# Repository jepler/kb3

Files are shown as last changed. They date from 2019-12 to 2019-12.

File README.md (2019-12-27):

# kb3 - OpenSCAD 3D printable keyboard with TKL layout

I was inspired by [the SiCK-68 keyboard on thingiverse](https://www.thingiverse.com/thing:3478494), but I favor the tenkeyless layout.
In particular, switching between the SiCK-68 and a TKL is difficult because of the compromise in placement of the escape key.
I realized that with a similar "two halves" design, I could print a full tenkeyless layout on my printer, but just barely.
That's when I started my own 3d printable keyboard design in OpenSCAD.

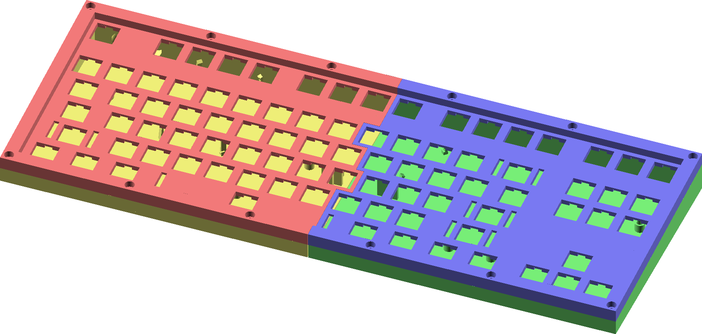
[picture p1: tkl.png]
3D Rendering


# Mechanicals

Aperture sizes are taken from direct measurements, from mechanical drawings of Cherry MX and Kailh keyswitches, and from the excellent (if somewhat bitrotted) [kad](https://github.com/swill/kad) program.
The stabilizer openings are for "Keystar" style stabilizers.

In contrast to SiCK-68, the case halves are joined with M3 screws into heat-set inserts.
Internal electronics are mounted via threaded inserts or little brackets, as appropriate.
A [panel-mount USB connector](https://www.adafruit.com/product/3258) is used, instead of situating the main microcontroller PCB at a fixed location.

# Electronics

This isn't done yet :)
The tenkeyless layout needs 23 I/Os for the "obvious" but inefficient matrix.
This can be dropped by 1 column pretty easily, allowing one pin left over
on an Itsy Bitsy (M4, M0, or AVR 32u4, not the upcoming nRF52840)

# Software

I plan to run CircuitPython, which will mean a need for new code.
CircuitPython can do basic HID (USB and Bluetooth).
However, as far as I've discovered, there aren't any libraries on top of that to facilitate keyboard layers, etc.

# OpenSCAD structure

`cherryplate.scad` functions as a library, and `tkl.scad` creates a particular keyboard.

# Status

See the issues page for items I know need to be worked on.

I think the 3D parts are complete.

# Contributing

I'm not sure this is ready for contributions or even issue reports yet.  
That said, stuff that would be great to do is:
 * Refactor `cherryplate.scad` so it is a good basis for further work
 * Pull items such as alignment pin locations into `cherryplate.scad`
 * Maybe an (external, Python or such) converter from www.keyboard-layout-editor.com layouts to my internal format
 * Contribute other layouts

# Bill of Material

*This bill of material is a work in progress.  Verify it yourself, don't order blindly*

(These are not affiliate links, but I do work for Adafruit)

| Item | Qty | Link | Comments |
|--|--|--|--|
| Filament | ~400g | | I used PLA |
| Keyswitches | 87 | | I'm using Kailh Purple |
| Costar Plate Mounted Clips | 2 * 5 | https://www.wasdkeyboards.com/cherry-mx-plate-mounted-stabilizer-clips-2pcs.html | |
| Costar Keycap Stabilizer Insert | 2 * 5 | https://www.wasdkeyboards.com/cherry-mx-keycap-stabilizer-insert-2pcs.html | |
| Costar Stabilizer Spring for 2x+ Keycaps | 4 * 5 | https://www.wasdkeyboards.com/cherry-mx-stabilizer-spring-for-2x-keycaps.html | |
| Costar Stabilizer Spring for Spacebar | 1 | https://www.wasdkeyboards.com/cherry-mx-stabilizer-spring-for-spacebar.html | |
| M3 x 4mm threaded inserts | 12 | https://www.mcmaster.com/94459A130 | |
| M2 x 2.5mm threaded inserts | 12 | https://www.mcmaster.com/94459A110 | |
| M3 x 8 screws | 12 | | |
| M2 x 6 screws | 8 | | |
| Neopixel strips | 4 | https://www.adafruit.com/product/1426 | |
| Itsy Bitsy M4 Express | 1 | https://www.adafruit.com/product/3800 | Or 32u4 or M0 |
| panel mount micro USB connector | 1 | https://www.adafruit.com/product/3258 | |
| Wiring | | | |

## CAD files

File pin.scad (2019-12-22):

intersection() {
    rotate([90,0,0])
    cylinder(d=3.9, h=16, $fn=32, center=true);

    cube([16, 16, 3.4], center=true);

    linear_extrude(height=6, center=true)
    polygon([
        [-0.5, -8.1],
        [-2.0, -4.1],
        [-2.0,  4.1],
        [-0.5,  8.1],
        [ 0.5,  8.1],
        [ 2.0,  4.1],
        [ 2.0, -4.1],
        [ 0.5, -8.1],
    ]);
}

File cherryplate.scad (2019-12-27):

// https://media.digikey.com/pdf/Data%20Sheets/Cherry%20PDFs/MX%20Series.pdf

////////////////////////////////////////////////////////////////////////
// micro b panel connector
// Overall width: 25mm
// Max height: 10mm (measured)
// Hole spacing: 18mm (per datasheet adafru.it/3258)
// Mounting screws: #4-40

// Create a void for the panel mount micro USB connector,
// connector pointing towards +Z, mounting holes aligned along X
module panelmicrob_void(d_front, d_back, h_spc = 18, maxh = 12, ovw = 26, h_dia =4.5 ) {
    d_ovl = d_back + d_front;
    // 1. Clearance holes for #4-40 screws, length d_front
    translate([-h_spc/2, 0, -.01])
    cylinder(d=h_dia, h=d_front+.01);
    translate([ h_spc/2, 0, -.01])
    cylinder(d=h_dia, h=d_front+.01);
    // 2. hole for the connector itself est 10x5mm
    translate([ 0, 0, -.01])
    linear_extrude(height=h_dia)
    square([11, 6],center=true);
    
    // 3. Cutout for the thing itself, length d_bac
    translate([0, 0, -d_back])
    linear_extrude(height=d_back)
    hull() {
        translate([-h_spc/2, 0, 0])
        circle(d=maxh);
        translate([ h_spc/2, 0, 0])
        circle(d=maxh);
    }
}
////////////////////////////////////////////////////////////////////////

$fn = 72;

function IN(x) = x * 25.4;

function rest(seq) = [for(i=[1:1:len(seq)-1]) seq[i]];
function reverse(seq) = seq ? concat(reverse(rest(seq)), [seq[0]]) : [];
function isnumber(x) = abs(x) + 1 >= 0;

$layer = 0;

module void_keyswitch() {
    square(IN(.551), center=true);
    if($layer == 1)
    square([IN(.551)/3, IN(.551)+3], center=true);
}

// 1x2, .. 1x2.75: A = .94
// 1x3: A = 1.5
// 1x7: A = 4.5
// 1x8, ..., 10: A = 5.25

$costar_stabilizer_offset_y = -0.65;
$costar_stabilizer_width = 3.3 + .1;
$costar_stabilizer_height = 14.2;
$costar_offset_layer = 5;
// kad uses +-1.65 in X and -6.45+7.75 for costar stabilizers
module void_keyswitch_stabilizer(A, B=0) {
    void_keyswitch();

    for(dx = [-A, A]) {
        translate([-dx, $costar_stabilizer_offset_y]) {
            square([$costar_stabilizer_width, $costar_stabilizer_height+$costar_offset_layer*$layer], center=true);
        }
    }
}

module void_keyswitch_as(N) {
    if(N <= 1.75) void_keyswitch();
    else if(N <= 2.75) void_keyswitch_stabilizer(11.9);
    else if(N <= 3) void_keyswitch_stabilizer(19.05);
    else if(N <= 4) void_keyswitch_stabilizer(28.575);
    else if(N <= 4.5) void_keyswitch_stabilizer(34.671);
    else if(N <= 5.5) void_keyswitch_stabilizer(42.8625);
    else if(N <= 6) void_keyswitch_stabilizer(47.5);
    else if(N <= 6.25) void_keyswitch_stabilizer(50);
    else if(N <= 7) void_keyswitch_stabilizer(50);
    else void_keyswitch_stabilizer(66.75);
}

module keyrow(widths) {
    if(widths) {
        width = widths[0];
        if(width > 0) {
            translate([IN(.375) * width, 0])
            void_keyswitch_as(width);
        }
        translate([IN(.75) * abs(width), 0])
            keyrow(rest(widths));
    }
}

module keyrowsr(rows) {
    if(rows) {
        row = rows[0];
        if(isnumber(row)) {
            translate([0, IN(.75) * row])
            keyrowsr(rest(rows));
        } else {
            translate([0, IN(.375)])
            keyrow(row);
            translate([0, IN(.75)])
            keyrowsr(rest(rows));
        }
    }
}

module keyrows(rows) { keyrowsr(reverse(rows)); }

module cutrows_r(rows, left, ovl) {
    if(rows) {
        row = rows[0];
        height = row[0];
        width = row[1];
        if(left) {
            translate([-IN(.375), -IN(.75)])
            offset(.125) square([width * IN(.75), height * IN(.75)]);
        } else {
            translate([-IN(.375) + width * IN(.75), -IN(.75)])
            offset(.125) square([ovl * IN(.75), height * IN(.75)]);
        }
        translate([0, height*IN(.75)])
        cutrows_r(rest(rows), left, ovl);
    }
}

module cutrows(rows, left=true, ovl=99) { cutrows_r(reverse(rows), left=left, ovl=ovl); }



module layer() {
    difference() {
        square([IN(.75 * $cells_x), IN(.75*$cells_y)]);
        keyrows($layout);
    }
}

$plate_th1 = 1.0;
$plate_th2 = 2.0;
$wall_th = 8;
$num_holes = 6;
$wall = 8;
m3_clearance = 3.6;
m3_counterbore_dia = 5.7;
m3_counterbore_h = 2.5;
m3_threaded_insert = 3.9;
m2_threaded_insert = 3.2;
$angle = 3.5;
$min_h = 8;
$floor = 2;

module m3_screw_counterbore(len, counterbore_depth=m3_counterbore_h) {
    cylinder(d=m3_clearance, h=len);
    translate([0,0,len-.01])
    cylinder(d=m3_counterbore_dia, h=counterbore_depth);
}

module m3_threaded_insert(len) {
    translate([0,0,-len+.01])
    cylinder(d=m3_threaded_insert, h=len);
}

module distribute(n, t) {
    echo("distribute", n, t);
    for(i=[0:1:n-1]) {
        translate(t * (i / (n-1))) children();
    }
}

module keeb() {

    translate([0,0,$plate_th2])
    linear_extrude($plate_th1, convexity=36) layer($layer=0);

    linear_extrude($plate_th2, convexity=36) layer($layer=1);

    difference() {
        linear_extrude($wall_th, convexity=2)
        difference() {
        translate([-$wall,-$wall,0])
        square([IN(.75 * $cells_x)+2*$wall, IN(.75*$cells_y)+2*$wall]);
        square([IN(.75 * $cells_x), IN(.75*$cells_y)]);
        }

        translate([-$wall/2, -$wall/2])
        distribute($num_holes, [IN(.75 * $cells_x) + $wall,0,0]) {
            m3_screw_counterbore(4, 8);

            translate([0, IN(.75*$cells_y)+$wall/2])
            translate([0, $wall/2])
            m3_screw_counterbore(4, 8);
        }

        let($stage = 1) children();
    }
}

module slice(left, delta, height=32, center=true) {
    linear_extrude(height, center=center, convexity=12)
    offset(delta=delta)
    cutrows($cut, left=left);
}
// %slice(false, delta=.2);

module divided_keyboard(left=1, right=1) {
    if(left)
    color("#ee7777") intersection() { keeb() children(); slice(true, delta=-.2); }
    if(right)
    color("#7777ee") render() intersection() { keeb() children(); slice(false, delta=-.2); }
}

module base_outline() {
    scale([1, 1/cos($angle), 1])
    difference() {
        translate([-$wall,-$wall,0])
        square([IN(.75 * $cells_x)+2*$wall, IN(.75*$cells_y)+2*$wall]);
        square([IN(.75 * $cells_x), IN(.75*$cells_y)]);
    }
}

module shear_yz(v) {
    multmatrix([ [1, 0, 0, 0],
                 [0, 1, v, 0],
                 [0, 0, 1, 0],
                 [0, 0, 0, 1]])
        children();
}

// construct the base with its bottom flat at Z=0
module base0() {
    render() {
        intersection() {
            rotate([$angle, 0, 0]) {
                translate([0,0,-500])
                cube(1000, center=true);
            }
            shear_yz(-tan($angle))
            translate([0, 0, -$min_h-.001]) {
                max_h = $min_h + sin($angle) * (IN(.85*$cells_y) + 2*$wall);
                linear_extrude(height=max_h, convexity=6) base_outline();

                translate([0,0,-$floor])
                scale([1, 1/cos($angle), 1])
                linear_extrude(height=$floor, convexity=6)
                translate([-$wall,-$wall,0])
                square([IN(.75 * $cells_x)+2*$wall, IN(.75*$cells_y)+2*$wall]);
            }
        }
    }
}

module m2_insert_riser(h, do_void) {
    if(do_void) {
        translate([0,0,-.5])
        cylinder(d=m2_threaded_insert, h=h+2);
    } else {
        cylinder(d=m2_threaded_insert + 3, h=h);
    }
}

module m3_insert_riser(h, do_void) {
    if(do_void) {
        translate([0,0,-.5])
        cylinder(d=m2_threaded_insert, h=h+2);
    } else {
        cylinder(d=m2_threaded_insert + 3, h=h);
    }
}

// put the base with the INTENDED TOP at z=0, slice off the unneeded part,
// add mounting holes for threaded insertts
module base_inplace() {
    difference() {

        intersection()  {
            union() {
                rotate([-$angle, 0, 0]) {
                    difference() {
                        union() {
                            render(convexity=4) base0();
                            let($stage=0) children();
                        }
                        let($stage=1) children();
                    }
                }
                let($stage=2) children();
            }
        }


        let($stage=3) children();

        translate([-$wall/2, -$wall/2])
        distribute($num_holes, [IN(.75 * $cells_x) + $wall,0,0]) {
            color("#ff0000")
            m3_threaded_insert(4);

            translate([0, IN(.75*$cells_y)+$wall/2])
            translate([0, $wall/2])
            color("#ff0000")
            m3_threaded_insert(4);
        }
    }
}

module base() {
    translate([0,0,$min_h])
    rotate([$angle, 0, 0])
    base_inplace() children();
}
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

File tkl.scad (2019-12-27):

// TODO 
// round or bevel top outside edges
// holes for mounting dowels
// check height
// check positions

use <cherryplate.scad>

module tkl() {
    let(
    $min_h = 8, // measured protrusion of switch 4mm, min_h = 8 let battery just clear plate, 1 more for slop/flex

    $pin_l = 20,
    $pin_d = 4,
    $cells_x = 18.5,
    $cells_y = 6.5,

    $layout = [
        [1, -1, 1, 1, 1, 1, -.5, 1, 1, 1, 1, -.5, 1, 1, 1, 1, -.5, 1, 1, 1],
        .5,
        [1, 1, 1, 1, 1, 1, 1, 1, 1, 1, 1, 1, 1, 2, -.5, 1, 1, 1],
        [1.5, 1, 1, 1, 1, 1, 1, 1, 1, 1, 1, 1, 1, 1.5, -.5, 1, 1, 1],
        [1.75, 1, 1, 1, 1, 1, 1, 1, 1, 1, 1, 1, 2.25, -.5],
        [2.25, 1, 1, 1, 1, 1, 1, 1, 1, 1, 1, 2.75, -1.5, 1],
        // [1.50, -1, 1.50, 7.0, 1.5, -1, 1.5, -.5, 1, 1, 1],
        [1.25, 1.25, 1.25, 6.25, 1.25, 1.25, 1.25, 1.25, -.5, 1, 1, 1],
    ],

    $cut = [
        [1, 10],
        [1, 10],
        [.5, 10],
        [1, 9.5],
        [1, 10],
        [1, 10.25],
        [1, 9.75],
        [1, 10.25],
        [1, 10.25]
    ],

    $num_holes = 6
    )
    children();

}
module base_cb() {
echo ("num_holes", $num_holes);
        ovl_x = IN(.75 * $cells_x) + 2*$wall;
        ovl_y = IN(.75 * $cells_y) + 2*$wall;
        // Alignment pins for the left and right halves
        if($stage == 1)  {
            translate([ovl_x * .5 - $wall, -.5*$wall, -$min_h/2-1])
            rotate([0,90,0])
            cylinder(d=$pin_d, h=$pin_l, center=true);

            translate([ovl_x * .5 - $wall, ovl_y-1.5*$wall, -$min_h/2-1])
            rotate([0,90,0])
            cylinder(d=$pin_d, h=$pin_l, center=true);

            translate([ovl_x * .5 - $wall, ovl_y-1.5*$wall, -$min_h/2 + 8])
            rotate([0,90,0])
            cylinder(d=$pin_d, h=$pin_l, center=true);
        }
        if($stage == 0 || $stage == 1) {
            for(x=[IN(.5), ovl_x-IN(.5)-2*$wall])
            translate([x, ovl_y/2, -$min_h])
            rotate(90)
            post_neopixel(3, $stage == 1);

            for(x=[ovl_x/2 - IN(3), ovl_x/2 + IN(3)])
            translate([x, IN(.5), -$min_h])
            post_neopixel(3, $stage == 1);
        }
        // itsy bitsy is 1.4 x .7
        if($stage == 0) {
            translate([ovl_x/2 - IN(2), ovl_y-IN(2), -$min_h-1])
            rotate(90)
            clip_itsybitsy(1.2);
        }
        // Anti-bowing posts
        if($stage == 2) {
            SUPP = [ [8.75, 3, 180], [10.5, 3, 0] ];
            intersection() {
                for( s = SUPP )
                {
                    translate([s[0], s[1], 0] * IN(.75))
                    rotate(s[2])
                    translate([-6,-1,-24])
                    linear_extrude(height=24, convexity=2)
                    union() {
                        square([12, 2]);
                        translate([4.5,0])
                        square([3, 5]);
                    }
                }
                rotate([-$angle,0,0])
                translate([0,0,500-$min_h])
                cube(1000, center=true);
            }
        }
        if($stage == 3) {
            // This Micro-B male/female extension cable features a male USB
            // Micro-B plug on one end, and a bulkhead mountable Micro-B female
            // receptacle on the other. The jack half has two mounting 'ears'
            // with 4-40 screws installed, 18mm apart. The ears are flexible so
            // the holes don't have to be drilled very precisely. The screws
            // can be put on from the back for 'reverse' mounting if the box
            // thickness is a problem. The entire unit is about 12" long from
            // tip to tip (with approx 10" cabling between connectors).

            
            translate([45, IN(.75*$cells_y)+$wall-2, -9])
            rotate(180)
            rotate([90,0,0])
            panelmicrob_void(12, 12);
        }
}

module keeb_cb() {
    ovl_x = IN(.75 * $cells_x) + 2*$wall;
    ovl_y = IN(.75 * $cells_y) + 2*$wall;
    if($stage == 1) {
            translate([ovl_x * .5 + IN(.75*.5) - $wall, -.5*$wall, .5*$wall])
            rotate([0,90,0])
            cylinder(d=$pin_d, h=$pin_l, center=true);

            translate([ovl_x * .5 - $wall + IN(.75*.25), ovl_y-1.5*$wall, .5*$wall])
            rotate([0,90,0])
            cylinder(d=$pin_d, h=$pin_l, center=true);
    }
}

part = 0;

tkl() {
echo("num_holes", $num_holes);
    if(part == 0) {
        spart = [0,1,0,1];
        divided_keyboard(spart[0], spart[1]) keeb_cb();;
        if(spart[2])
        color("#eeee77")
        split_base(true, false, inplace=true) base_cb();
        if(spart[3])
        color("#77ee77")
        render() split_base(false, true, inplace=true) base_cb();
    }
    if(part == 1) {
        split_base(true) base_cb();
    }
    if(part == 2) {
        split_base(false, true) base_cb();
    }
    if(part == 3) {
        divided_keyboard(1,0) keeb_cb();;
    }
    if(part == 4) {
        divided_keyboard(0,1) keeb_cb();;
    }

    if(part == -1) {
        projection(cut=true)
        translate([0,0,-4])
        split_base(true) base_cb();
    }
    if(part == -2) {
        projection(cut=true)
        translate([0,0,-4])
        split_base(false, true) base_cb();
    }
}

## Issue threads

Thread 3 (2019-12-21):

plate mounts: verify threaded insert diameter

jepler, 2019-12-21:
This felt a little tight.

Closed 2019-12-31.

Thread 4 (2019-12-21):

BOM for mechanical parts

jepler, 2019-12-21:
Add a BOM for mechanical parts.  Correct links for the threaded inserts are especially important.  Document screw lengths.

Closed 2019-12-22.

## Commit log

2019-12-21 Add a sketch of a BOM
2019-12-22 tweak inserts
    [cherryplate.scad]
2019-12-22 tweak pins
    [tkl.scad]
2019-12-22 pin: new file
    [pin.scad]
2019-12-26 adjust costar stabilizer geometry
    this is tested :)
    [cherryplate.scad]
2019-12-26 adjust internal size for key clearance
    [cherryplate.scad, tkl.scad]
2019-12-27 switch from feather+seesaw to itsybitsy
    [cherryplate.scad, tkl.scad]
2019-12-27 fix neopixel post geometry
    [cherryplate.scad, tkl.scad]
2019-12-27 shorter case works now
    [cherryplate.scad, tkl.scad]
2019-12-27 make pin holes less oversized
    [tkl.scad]
2019-12-27 fix rendering error for supports
    [tkl.scad]
2019-12-27 fix pin placement on top
    [tkl.scad]
